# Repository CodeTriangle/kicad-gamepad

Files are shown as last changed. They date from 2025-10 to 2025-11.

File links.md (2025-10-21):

https://roboticworx.io/blogs/projects/build-custom-stm32s-from-scratch-tutorial
https://blnlabs.com/how-to-add-usb-type-c-to-esp32-development-board/

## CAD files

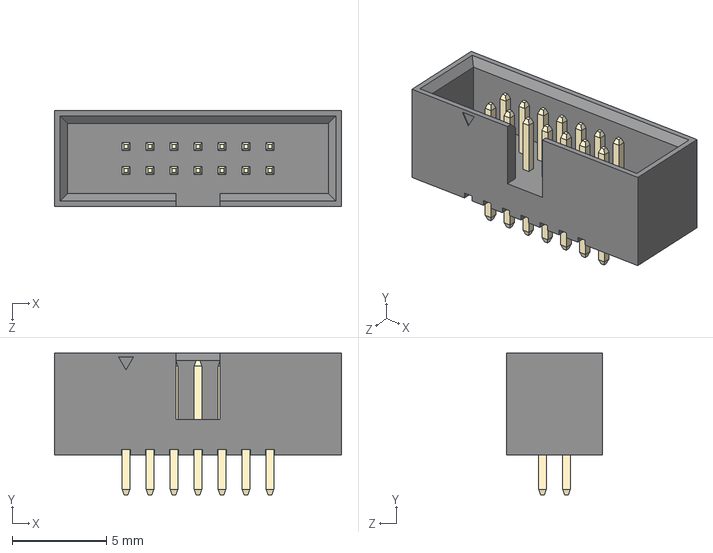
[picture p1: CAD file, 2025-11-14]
models/3220-14-0100-00.step
15.2 x 7.50 x 5.10 mm
3220-xx-0100-00 body_14
Pin^3220-xx-0100-00 x 14

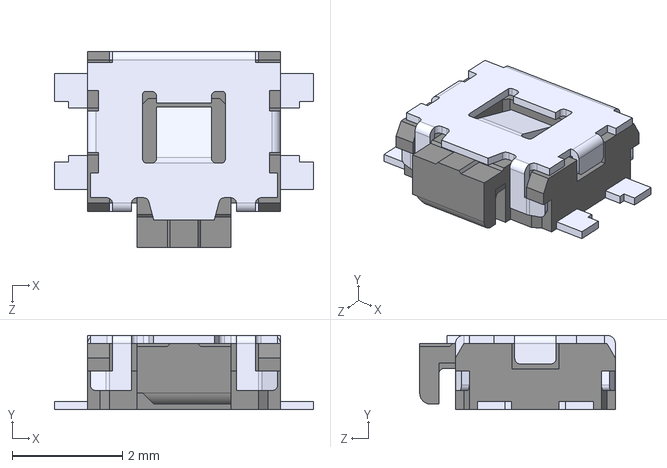
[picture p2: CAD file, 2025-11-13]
models/EVQ-P7A01P.step
4.70 x 1.35 x 3.55 mm

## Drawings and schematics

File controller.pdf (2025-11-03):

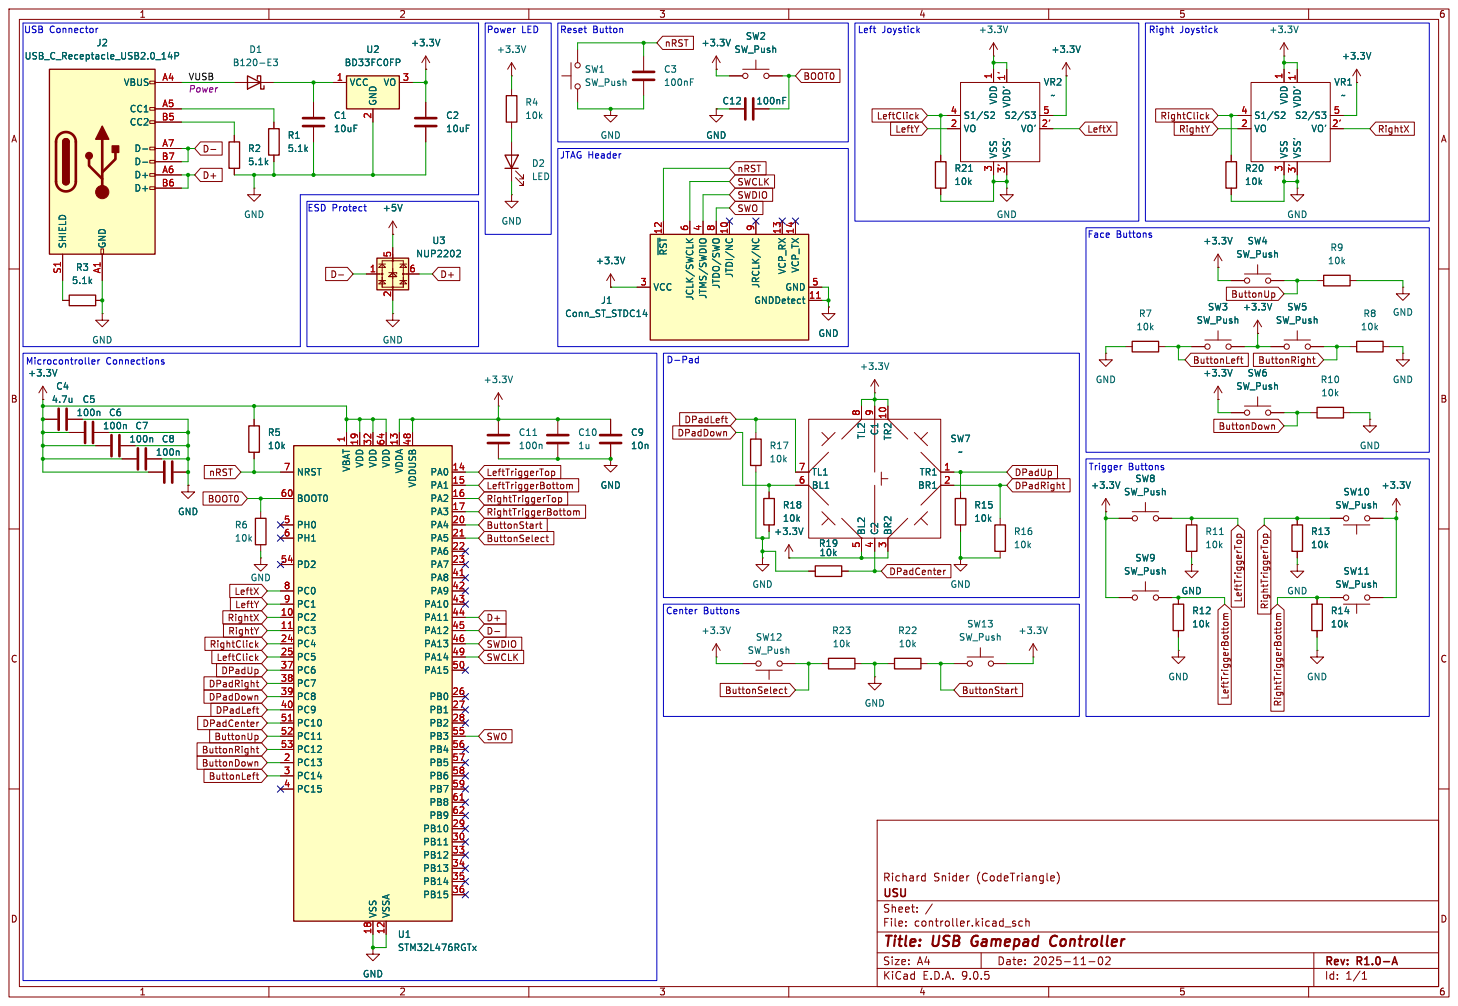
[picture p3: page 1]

nRST DPadUp DPadDown ButtonUp

8 JTDI/NC 10 JRCLK/NC

1 VDD 19 VDD 32 VSS 18 VDD 64 VSSA 12 VDDA 13 VDDUSB 48 PA0 14 PA1 15 PA2 16 PA3 17 PA4 20 PA5 21 PA6 22 PA7 23 PA8 41 PA9 42 PA10 43 PA11 44 PA12 45 PA13 46 PA14 49 PA15 50 PB0 26 PB1 27 PB2 28 PB3 55 PB4 56 PB5 57 PB6 58 PB7 59 PB8 61 PB9 62 PB10 29 PB11 30 PB12 33 PB13 34 PB14 35 PB15 36 U1STM32L476RGTx

1 VDD 19 VDD 32 VSS 18 VDD 64 VSSA 12 VDDA 13 VDDUSB 48 PA0 14 PA1 15 PA2 16 PA3 17 PA4 20 PA5 21 PA6 22 PA7 23 PA8 41 PA9 42 PA10 43 PA11 44 PA12 45 PA13 46 PA14 49 PA15 50 PB0 26 PB1 27 PB2 28 PB3 55 PB4 56 PB5 57 PB6 58 PB7 59 PB8 61 PB9 62 PB10 29 PB11 30 PB12 33 PB13 34 PB14 35 PB15 36 GND

Id: 1/1 Title: USB Gamepad Controller File: controller.kicad_sch Sheet: / USU

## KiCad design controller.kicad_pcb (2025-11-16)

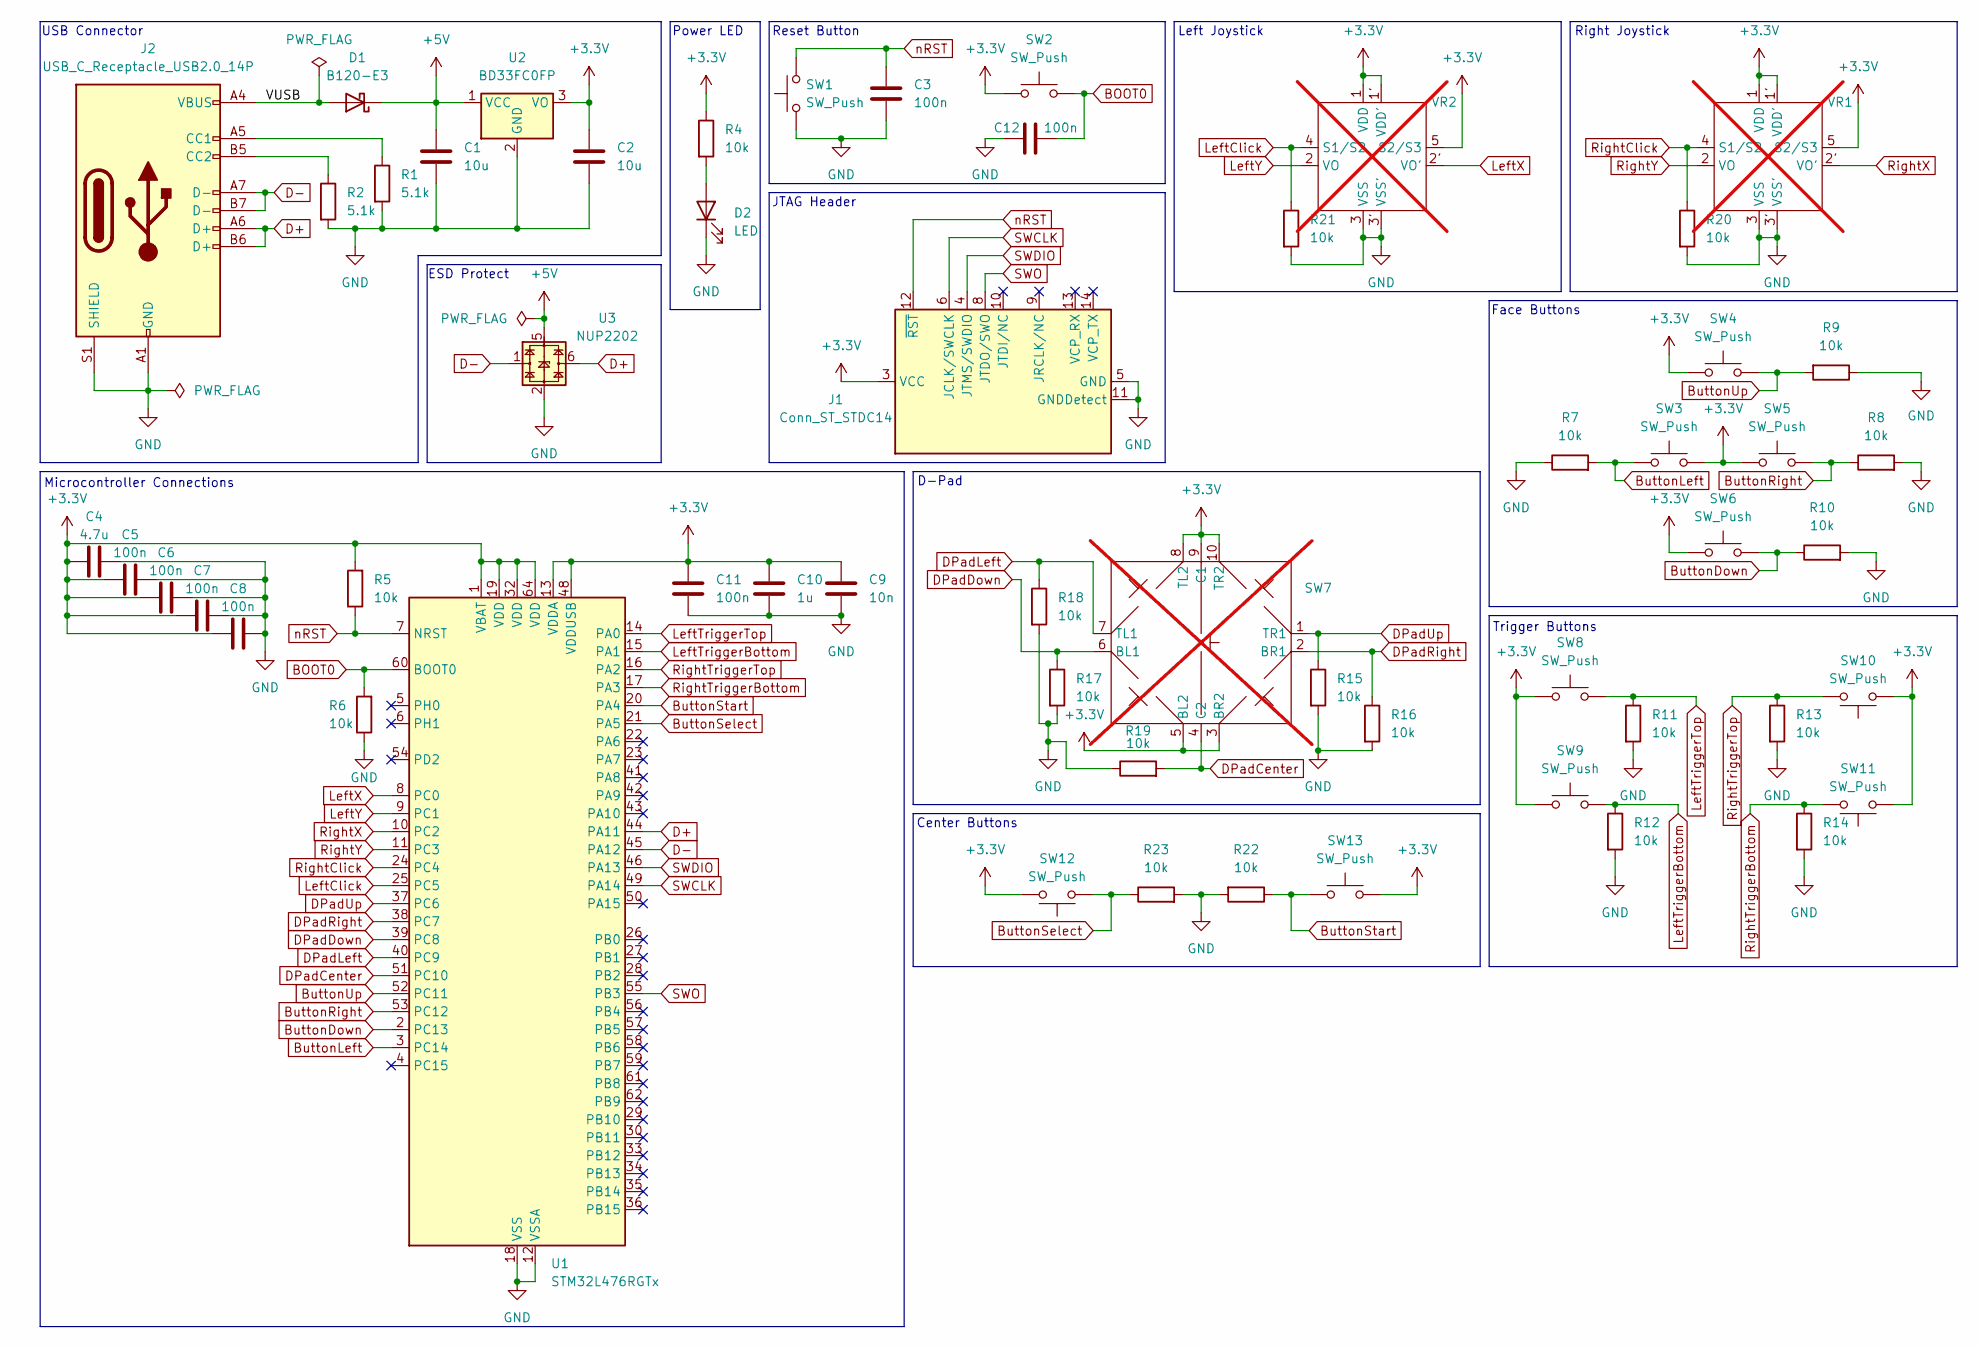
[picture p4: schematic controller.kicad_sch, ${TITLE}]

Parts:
C1, C2: 10u; C_0402_1005Metric; MPN GRM155R61A106ME11D
C3, C5, C6, C7, C8, C11, C12: 100n; C_0201_0603Metric; MPN GRM033C71C104KE14D
C4: 4.7u; C_0201_0603Metric; MPN GRM035R60J475ME15D
C9: 10n; C_0201_0603Metric; MPN GRM033R71A103KA01D
C10: 1u; C_0201_0603Metric; MPN CL03A105MQ3CSNC
D1: B120-E3; D_SMA; MPN B120-E3/61T
D2: LED; LED_0201_0603Metric; MPN CSP0603AN101-WP30300563001-3T
J1: Conn_ST_STDC14; CONN14_3220-14_CNC; MPN 3220-14-0100-00
J2: USB_C_Receptacle_USB2.0_14P; USB_C_Receptacle_GCT_USB4085; MPN USB4085-GF-A
R1, R2: 5.1k; R_0201_0603Metric; MPN RC0201FR-075K1L
R4, R5, R6, R7, R8, R9, R10, R11, R12, R13, R14, R15, R16, R17, R18, R19, R20, R21, R22, R23: 10k; R_0201_0603Metric; MPN CRCW020110K0FNED
SW1, SW2: SW_Push; SW_Push_1P1T_NO_CK_KMR2; MPN Y78B21110FP
SW3, SW4, SW5, SW6: SW_Push; SW_Push_1P1T_NO_CK_PTS125Sx43SMTR; MPN 10913247
SW7: K1-1210UN-01; not fitted
SW8, SW9, SW10, SW11: SW_Push; SW_EVQ-P7A01P_Single; MPN EVQ-P7A01P
SW12, SW13: SW_Push; SW_PUSH_6mm; MPN 1301.9302
U1: STM32L476RGTx; LQFP-64_10x10mm_P0.5mm; MPN STM32L476RGT6
U2: BD33FC0FP; TO-252-2; MPN BD33FC0FP-E2
U3: NUP2202; SOT-363_SC-70-6; MPN NUP2202W1T2G
VR1, VR2: 3D16A1N; not fitted

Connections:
+3.3V: C2.2, C4.2, C5.1, C6.1, C7.1, C8.1, C9.2, C10.2, C11.2, J1.3 (VCC), R4.1, R5.2, SW2.1, SW3.2, SW4.1, SW5.1, SW6.1, SW7.3 (BR2), SW7.5 (BL2), SW7.8 (TL2), SW7.9 (C1), SW7.10 (TR2), SW8.1, SW9.1, SW10.1, SW11.1, SW12.2, SW13.2, U1.1 (VBAT), U1.13 (VDDA), U1.19 (VDD), U1.32 (VDD), U1.48 (VDDUSB), U1.64 (VDD), U2.3 (VO), VR1.1 (VDD), VR1.1' (VDD'), VR1.5 (S2/S3), VR2.1 (VDD), VR2.1' (VDD'), VR2.5 (S2/S3)
+5V: C1.1, D1.1 (K), U2.1 (VCC), U3.5
/VUSB: D1.2 (A), J2.A4 (VBUS), J2.A9 (VBUS), J2.B4 (VBUS), J2.B9 (VBUS)
BOOT0: C12.1, R6.2, SW2.2, U1.60 (BOOT0)
ButtonDown: R10.1, SW6.2, U1.2 (PC13)
ButtonLeft: R7.2, SW3.1, U1.3 (PC14)
ButtonRight: R8.1, SW5.2, U1.53 (PC12)
ButtonSelect: R23.1, SW12.1, U1.21 (PA5)
ButtonStart: R22.1, SW13.1, U1.20 (PA4)
ButtonUp: R9.2, SW4.2, U1.52 (PC11)
D+: J2.A6 (D+), J2.B6 (D+), U1.44 (PA11), U3.6
D-: J2.A7 (D-), J2.B7 (D-), U1.45 (PA12), U3.1
DPadCenter: R19.2, SW7.4 (C2), U1.51 (PC10)
DPadDown: R17.1, SW7.6 (BL1), U1.39 (PC8)
DPadLeft: R18.1, SW7.7 (TL1), U1.40 (PC9)
DPadRight: R16.1, SW7.2 (BR1), U1.38 (PC7)
DPadUp: R15.1, SW7.1 (TR1), U1.37 (PC6)
GND: C1.2, C2.1, C3.1, C4.1, C5.2, C6.2, C7.2, C8.2, C9.1, C10.1, C11.1, C12.2, D2.1 (K), J1.5 (GND), J1.7 (GND), J1.11 (GNDDetect), J2.A1 (GND), J2.A12 (GND), J2.B1 (GND), J2.B12 (GND), J2.S1 (SHIELD), R1.2, R2.2, R6.1, R7.1, R8.2, R9.1, R10.2, R11.2, R12.2, R13.2, R14.2, R15.2, R16.2, R17.2, R18.2, R19.1, R20.2, R21.2, R22.2, R23.2, SW1.1, U1.12 (VSSA), U1.18 (VSS), U1.31 (VSS), U1.47 (VSS), U1.63 (VSS), U2.2 (GND), U3.2, VR1.3 (VSS), VR1.3' (VSS'), VR2.3 (VSS), VR2.3' (VSS')
LeftClick: R21.1, U1.25 (PC5), VR2.4 (S1/S2)
LeftTriggerBottom: R12.1, SW9.2, U1.15 (PA1)
LeftTriggerTop: R11.1, SW8.2, U1.14 (PA0)
LeftX: U1.8 (PC0), VR2.2' (VO')
LeftY: U1.9 (PC1), VR2.2 (VO)
unnamed: D2.2 (A), R4.2
unnamed: J2.A5 (CC1), R1.1
unnamed: J2.B5 (CC2), R2.1
RightClick: R20.1, U1.24 (PC4), VR1.4 (S1/S2)
RightTriggerBottom: R14.1, SW11.2, U1.17 (PA3)
RightTriggerTop: R13.1, SW10.2, U1.16 (PA2)
RightX: U1.10 (PC2), VR1.2' (VO')
RightY: U1.11 (PC3), VR1.2 (VO)
SWCLK: J1.6 (JCLK/SWCLK), U1.49 (PA14)
SWDIO: J1.4 (JTMS/SWDIO), U1.46 (PA13)
SWO: J1.8 (JTDO/SWO), U1.55 (PB3)
nRST: C3.2, J1.12 (~RST), R5.1, SW1.2, U1.7 (NRST)

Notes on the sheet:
D-Pad
Right Joystick
Trigger Buttons
ESD Protect
Microcontroller Connections
Power LED
JTAG Header
Reset Button
Face Buttons
Left Joystick
Center Buttons
USB Connector

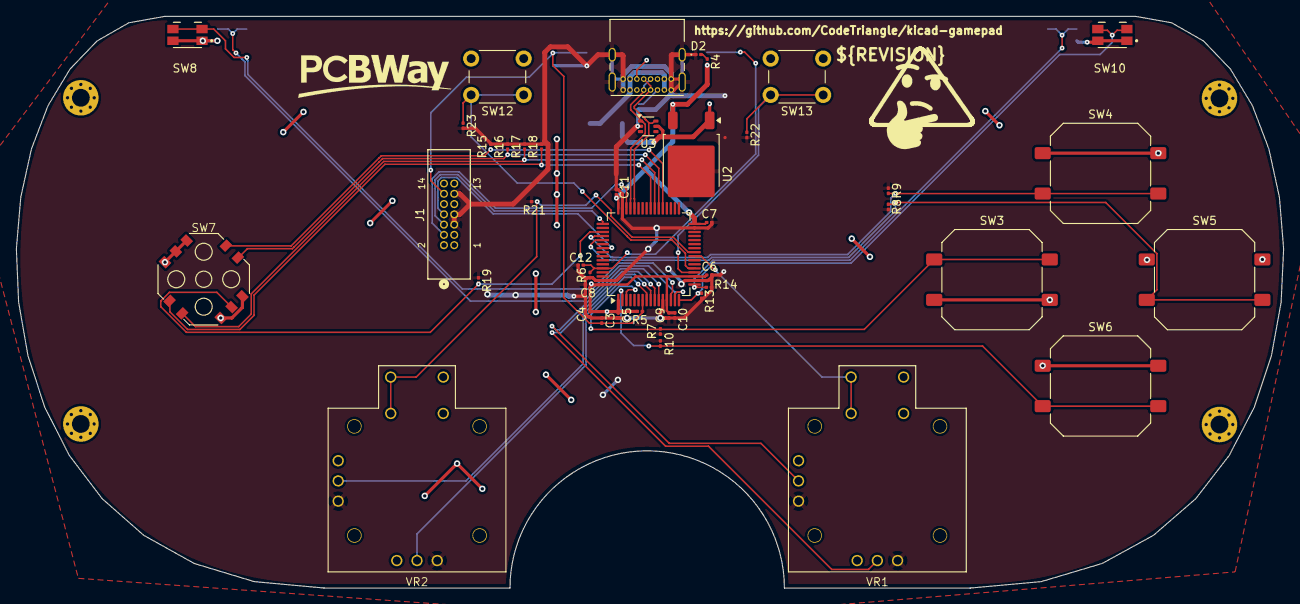
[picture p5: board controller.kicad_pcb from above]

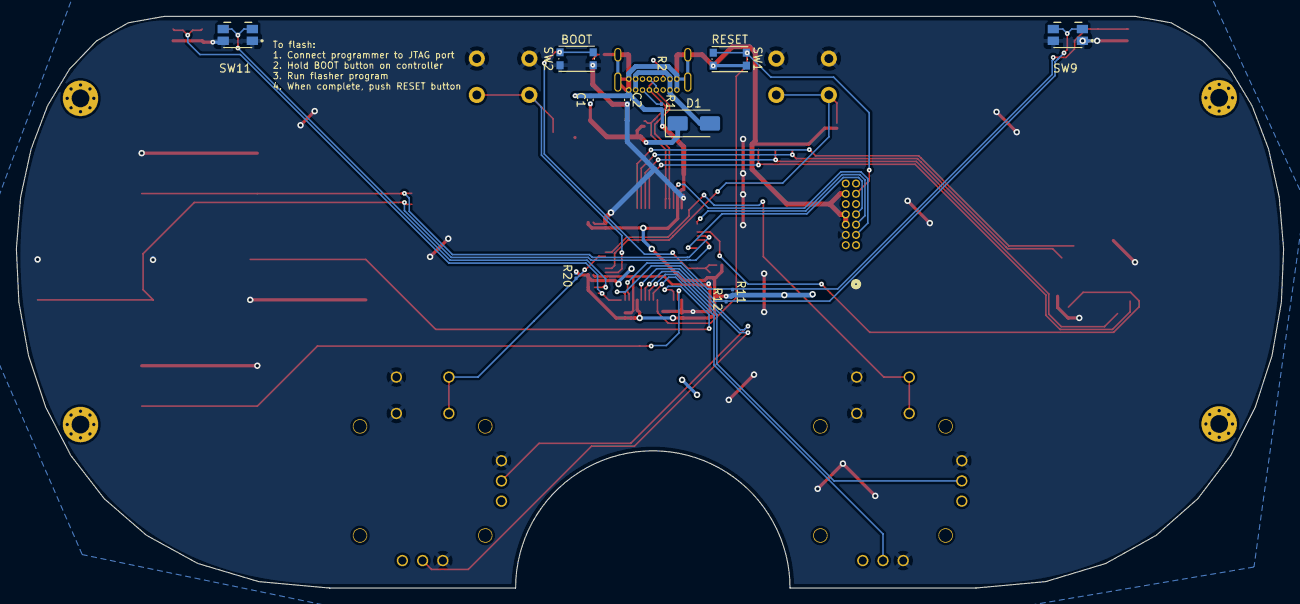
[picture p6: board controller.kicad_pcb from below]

Board: 2 copper layers, 156.8 x 70.7 mm, 56 parts (12 on the bottom side), 35 nets.

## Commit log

2025-10-23 place a bunch of components
    [controller.kicad_pcb]
2025-10-25 initial ground/power routing
    [controller.kicad_pcb, controller.kicad_sch]
2025-10-25 a bit more power routing
    [controller.kicad_pcb]
2025-10-25 change to receptacle
    [controller.kicad_pcb, controller.kicad_sch]
2025-10-25 fix some DRC checks
    [controller.kicad_pcb]
2025-10-26 fix pin assignments
2025-10-26 add some control components to schematic and pcb
    [controller.kicad_pcb, controller.kicad_sch]
2025-11-02 finish routing, more or less
    [controller.kicad_pcb, controller.kicad_sch]
2025-11-02 fix most drc issues
    [controller.kicad_pcb]
2025-11-02 add vanity
    [controller.kicad_pcb]
2025-11-03 add start and select + resistors to all other buttons
    [controller.kicad_pcb, controller.kicad_sch]
2025-11-03 fix ERC and add metadata
    [controller.kicad_pcb, controller.kicad_sch]
2025-11-03 add fabrication files
    [controller.kicad_pcb, controller.kicad_sch]
2025-11-06 set DNP flags
    [controller.kicad_sch]
2025-11-13 move symbol and footprint libraries to own folder
2025-11-13 add button and connector components
    [EVQ-P7A01P.step]
2025-11-13 add bom numbers
    [controller.kicad_sch]
2025-11-13 update pcb to reflect new footprints
    [controller.kicad_pcb]
2025-11-14 some minor trace changes
    [controller.kicad_pcb, controller.kicad_sch]
2025-11-14 add pcbway logo and some more trace modifications
    [controller.kicad_pcb]
2025-11-14 change NPTHs on joystick footprint
    [controller.kicad_pcb]
2025-11-14 final commit before i do something really silly
    [controller.kicad_pcb]
2025-11-14 modify stdc14 connector footprint
    [3220-14-0100-00.step]
2025-11-14 add 3220 component
    [controller.kicad_pcb, controller.kicad_sch]
2025-11-14 change some more tracks
    [controller.kicad_pcb]
2025-11-14 change symbol properties to new version
    [controller.kicad_sch]
2025-11-14 tweak again
    [controller.kicad_pcb]
2025-11-14 normalize text
    [controller.kicad_pcb]
2025-11-16 final few fixes; R1.1-A
    [controller.kicad_pcb, controller.kicad_sch]
